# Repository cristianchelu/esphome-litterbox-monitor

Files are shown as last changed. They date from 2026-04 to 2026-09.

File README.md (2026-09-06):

# ESPHome Litterbox Monitor

A DIY smart litterbox: four load cells under the box, an HX711, and an
ESP32 running ESPHome. A state analyzer on the chip turns the raw 10 Hz
weight signal into everything listed below — no camera, no cloud, no
external compute — and surfaces it in Home Assistant as native sensors,
buttons, and actions.

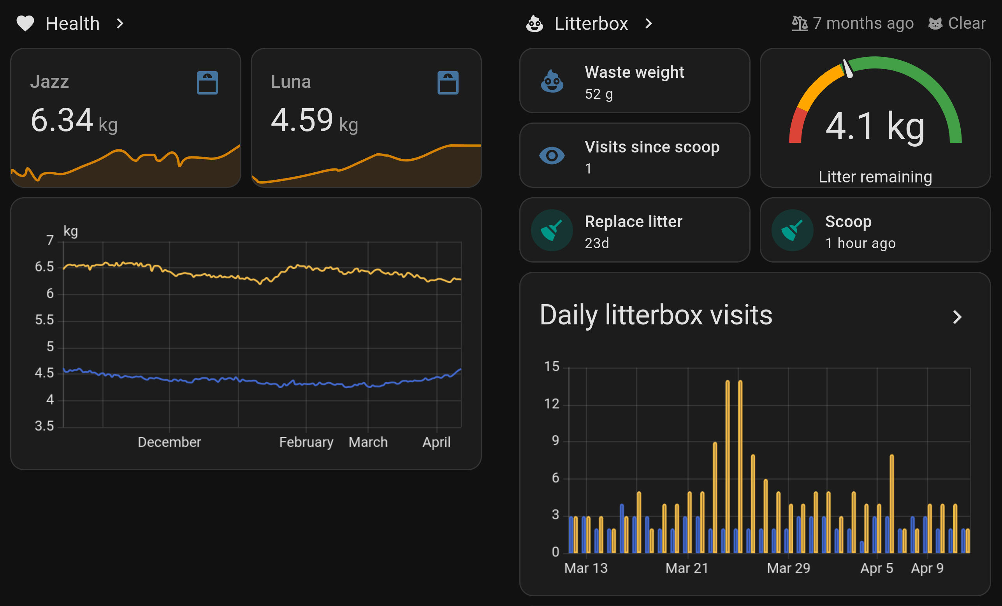
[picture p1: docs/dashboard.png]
Dashboard Overview


## Features

- **Knows which cat is which.** Identifies visiting cats by weight (up to 5)
  and tracks each cat's weight over time — no collars, no cameras.
- **Logs every visit.** Per-cat daily counts of visits, pees, and poops,
  plus visit duration and total visits since the last scoop.
- ***PoopSense.*** Tells #1 from #2 using nothing but the weight signal.
  [How it works ->](docs/POOPSENSE.md)
- **Tells you when to scoop.** Tracks how much waste has piled up since the
  last clean — and detects the clean itself, so the counters reset on their
  own when you scoop.
- **Tells you when to deep clean, and notices when you do.** Configurable
  reminder for full litter changes; put the washed box back empty and the
  timer restarts on its own. [How it works ->](docs/BOX_TRACKING.md)
- **Watches the litter level.** Estimates how much litter is left in the box
  so you know when to top up, and counts each bag you pour in.
- **Takes care of itself.** Re-zeroes against the bare board whenever the box
  comes off, and tells a scoop from a top-up from you lifting the whole thing
  to clean underneath.

## What You Need

### Load cells

- 4× strain gauge load cells, one per corner of the baseboard (commonly
  available on AliExpress); 5-12.5 kg each covers most setups.
- Sizing is a balancing act: strong enough to survive the cat's landing,
  small enough that PoopSense can still see grams. For a typical
  single-cat setup, 4× 6-8 kg cells hit the sweet spot.
- The full math — sizing formula, worked examples, and resolution table —
  lives in the **[load cell sizing guide](docs/LOAD_CELLS.md)**.

### Load cell amplifier (HX711)

- Any HX711 breakout board will work, BUT:
- Boards with separate `VCC` (5V for load cells) and `VDD` (3.3V for ESP32 logic) are recommended for best accuracy.
  - Recommended, known good example: [Sparkfun HX711 v1.1](https://www.sparkfun.com/sparkfun-load-cell-amplifier-hx711.html)
  - _BEWARE_ Some no-name breakout boards have separate `VCC` and `VDD` pins but
    electrically tie them together. Supplying 5V to these _will_ kill the esp chip.
    Validate these with a multimeter before applying power.

### ESP32

- Use a variant with a **hardware FPU**: the classic ESP32 (what the
  config targets and the development build runs) or the ESP32-S3.
- PoopSense leans on float math — per-sample filtering at 10 Hz and
  standard-deviation crunching at 0.1 g precision after every visit — so
  variants that emulate floats in software (S2, C3, C6) are untested.

### Litterbox and base

- For large breeds, the [IKEA SAMLA 79x57x18 cm/55 l](https://www.ikea.com/us/en/p/samla-box-with-lid-clear-s39440814/#content)
  is a good DIY litterbox.
- Can be paired with a suitable [IKEA KOMPLEMENT](https://www.ikea.com/gb/en/p/komplement-shelf-white-90277961/)
  shelf as a base.

### Calibration tools

You'll also want these on hand for the calibration step later:

- A known good kitchen scale.
- A bathroom scale (for weighing the cats).
- Calibration weights adding up to roughly your everyday load — box +
  litter + cat (~20 kg on the XL build). Several small water bottles work
  great; one big jug does not — see [Calibration](#calibration) for why.

## Assembly

Follow this great [SparkFun HX711 Hookup Guide](https://learn.sparkfun.com/tutorials/load-cell-amplifier-hx711-breakout-hookup-guide/all)
for wiring the load cells to the HX711 and mounting them under the baseboard.

Wire the HX711 to the ESP32. The configuration defaults to:

| HX711 pin | ESP32 pin |
|---|---|
| `DOUT` / `DT` | `GPIO16` |
| `SCK` / `CLK` | `GPIO4` |

You can use different pins — just update the `hx711` sensor section of the
YAML to match your wiring.

## Firmware Setup

1. Clone this repo (or copy both [`litterbox-monitor.yaml`](litterbox-monitor.yaml)
   and [`state_analyzer.h`](state_analyzer.h) into the same directory — both
   files are required).

2. Create a `secrets.yaml` next to them defining:
   `wifi_ssid`, `wifi_password`, `litterbox_api_key`, `litterbox_ota_password`,
   and `litterbox_ap_password`.

3. Edit the `substitutions` block at the top of the YAML:

   - **`cats`** — your cat names (e.g. "Fluffy", "Whiskers", "Mittens").
     1-5 cats are supported; add or remove entries as needed. Only the cats
     you define will have corresponding weight and daily visit sensors in
     Home Assistant, so configure this before first flashing. (After
     flashing, you'll set each cat's weight with the `set_cat_weight`
     action — see [Calibration](#calibration).)
   - **`timezone`** — your local timezone (used by the daily counters).

4. If you wired the HX711 to different GPIO pins, update the `hx711` sensor
   section accordingly (see [Assembly](#assembly)).

5. Flash with ESPHome as usual.

## Calibration

1. Gather calibration weights adding up to roughly what the cells will
   carry day to day — box + litter + cat (~20 kg on the XL build) — and
   measure them to the nearest gram in batches your kitchen scale is
   comfortable with (2 L bottles, two at a time, on a "5 kg max" scale).

   Several small bottles at working load beat one big jug: scales are
   only accurate mid-range — [here's why](docs/LOAD_CELLS.md#the-calibration-weight).

2. Set the `Calibration Known Weight` number entity to the weight
   you measured (in grams).

3. Make sure the constructed base is **without anything on top**, resting on
   a **flat and level** surface. Use shims if you need to.

4. Press the `Calibrate Scale` button. This will capture the zero point (tare).

5. Place the known weights on the base and press the `Calibrate Scale`
   button again. This will complete the calibration process.

   The "Raw weight" sensor should now read the weight you placed on it,
   and the "Calibration Last Performed" sensor should read the current time.
   If this is not the case, consult the ESPHome logs for errors and repeat
   steps 2-5.

6. ***Optional*** Fill in "Empty Box Weight" number entity to the weight of the
    empty litterbox (in grams). This will improve the accuracy of the
    "Litter Remaining" sensor, and it is how a deep clean is recognised: the
    box coming back within 150 g of this weight. You can place the box on the
    monitor and read the "Raw weight" sensor to get this value.

7. Set the litterbox on top, add the litter and trigger the `Reset clean` button.

   ***Optional*** Copy the "Litter Remaining" reading into the "Full Litter
   Weight" number entity to get "Litter Level" percentage estimates.

8. Take the approximate weight of your cats (within 10%).

   This can be easily done with weighing yourself on a bathroom scale,
   then weighing yourself again while holding each cat, and
   subtracting the difference.

   Use the `set_cat_weight` action within Home Assistant to set
   an initial value for each cat's weight, in the order you defined them
   in the configuration (see [Actions](#actions-services) below).

That's it — the monitor is ready to use.

## Reference

### Sensors and Entities

- **Cat 1-5 Weight:** Last weight stored for each cat when PoopSense identifies
  them on a visit (only enabled cats are visible).
- **Cat 1-5 Daily Visits:** Number of visits per day for each cat (only enabled cats are visible).
- **Cat 1-5 Daily Pee:** Number of urination events today for each cat (only enabled cats are visible).
- **Cat 1-5 Daily Poops:** Number of defecation events today for each cat (only enabled cats are visible).
- **Elimination Type:** Text sensor reporting `no_elimination`,
  `urination`, `defecation`, `both`, or `unknown` after each analyzed activity.
- **Event Duration:** Seconds for the activity window that was analyzed (updated
  when PoopSense runs at the end of activity).
- **Waste Weight:** Estimated total accumulated waste (grams) since last clean.
- **Litter Remaining:** Estimated remaining litter (kg).
- **Litter Level:** The same estimate as a percentage of "Full Litter Weight".
  Unavailable until you set that number.
- **Visits:** Number of cat visits since last clean.
- **Deep Clean Timer:** Days left until next recommended deep clean / litter change.
- **Deep Clean Due:** The same deadline as a timestamp, so it survives reboots
  on both ends and shows up before the clock has synced.
- **Calibration Last Performed:** Timestamp of the last completed scale
  calibration. Unavailable until one has been run.
- **Litter Added:** Grams poured in at the last top-up or deep clean.
- **Maintenance:** Event entity that fires `scoop`, `top_up`, `deep_clean` or
  `lifted` (the whole monitor was picked up and put back) once the counters
  have been updated. Use it as an automation trigger.
  [How it works ->](docs/BOX_TRACKING.md)
- **Cat Weight:** Diagnostic sensor (disabled by default) showing the cat weight
  in kg from the last PoopSense result.
- **Elimination Std Dev:** Diagnostic; the standard deviation (grams) of the
  elimination window PoopSense classified last. Compare it with the
  Classification Threshold when tuning.
- **State Machine:** Diagnostic text sensor with the analyzer's current
  phase: `empty`, `entering`, `occupied`, `eliminating` or `gap`.
- **Occupancy, Activity, Vibration:** Diagnostic sensors for physical presence,
  combined activity, and scale jitter.
- **Cat Event:** Diagnostic occupancy-style hint when tared weight is close to a
  known cat for 2+ seconds (used internally for activity; PoopSense does the
  full visit analysis when activity ends).
- **Box State:** Diagnostic text sensor: `normal`, `lifted` (monitor in the
  air), `off` (bare board) or `empty` (washed box back, nothing in it yet).
- **Measured Box Weight:** Diagnostic; what the empty box weighed when it last
  came back from a deep clean, to compare with the Empty Box Weight setting.
- **Zero Drift:** Diagnostic; what the bare board read the last time the box
  was off, before the zero was corrected.
- **Raw/Unfiltered/Tared Weight:** Diagnostic weight readings.
- **Analog sensor value:** Diagnostic (disabled by default); the raw HX711
  count before calibration is applied.
- **WiFi Signal:** Diagnostic RSSI in dBm, published once a minute as the median
  of four samples.

### Number Entities

- **Litter Change Interval:** Configure the number of days between deep clean reminders (7-30 days, default: 30).
- **Classification Threshold:** Standard deviation threshold (in grams) that separates urination from defecation. The default of 4 g works well out of the box; raise it if defecation events are being over-reported, lower it if they're being missed.  See [PoopSense](docs/POOPSENSE.md) for details.
- **Calibration Known Weight:** Weight of calibration objects used during scale setup.
- **Empty Box Weight:** Weight of the empty litterbox for improved litter remaining calculations. Also what deep-clean detection compares against; left at 0, deep cleans are not detected.
- **Full Litter Weight:** How much litter (in kg) a freshly filled box holds — what the "Litter Level" percentage counts as 100%. Left at 0, that sensor stays unavailable.

### Buttons

- **Reset Deep Clean Timer:** Resets the deep clean countdown.
- **Reset Clean:** Resets tare, litter, waste, and visit counters.

  Only required if the automatic clean detection failed.
- **Calibrate Scale:** Runs the two-step calibration: first press tares the
  bare board, second press (with the known weight on) sets the span. See
  [Calibration](#calibration).

### Actions (Services)

- `set_cat_weight`: Set a cat's weight manually via Home Assistant or API.
  - Parameters: `cat` (int, 1-5), `weight` (float)
  - Example: To set Cat 1's weight to 5.2kg, call `set_cat_weight` with `cat=1`, `weight=5.2`.

### Synchronize Multiple Litterboxes

Running more than one litterbox? Keep the cat weights in sync with a small
Home Assistant automation: when a cat's weight updates on one box, call
`set_cat_weight` on the others.

## Roadmap

- [x] Runtime assisted calibration.
- [x] Easier adding/removing of pets.
- [x] Distinguish urination/defecation/no-waste events.
- [x] Automatic zero calibration whenever the box comes off the board.
- [ ] Calculate trends and alert for outliers.
- [ ] Distinguish cats of similar weight.
- [x] Automatic deep clean detection.
- [x] Litter top-up detection.
- [ ] Error state detection (debris stuck underneath, box misaligned)

## Acknowledgements

- [Andy Bradford's Blog post](https://andybradford.dev/2022/06/02/internet-of-poop-how-and-why-i-built-a-smart-litter-tray/)
  for the initial inspiration
- [markusressel/ESPHome-Smart-Scale](https://github.com/markusressel/ESPHome-Smart-Scale) for
  the auto-tare smart scale code
- [DIY Cat Village](https://www.youtube.com/watch?v=PIszxXKy8H4) Youtube channel for the IKEA litterbox hack
- [Purina Petivity](https://www.petivity.com/products/smart-litter-box-monitor)
  for not offering an XL version and propelling this DIY project.

## Contributing

Feel free to open an issue or pull request.

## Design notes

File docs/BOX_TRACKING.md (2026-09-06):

# Box Tracking

PoopSense figures out what the cat did. Box tracking figures out what *you*
did: scooped, topped up, deep cleaned, or picked the whole thing up to clean
under it. Each of those leaves a shape in the weight signal that a cat can't
make, and the firmware uses them to keep the litter and waste counters right
without being told.

## How it works

Everything runs on the **absolute** weight (calibrated, not tared), so the
bare board reads 0 g and an empty box reads "Empty Box Weight". That makes
the shapes unambiguous where event-relative deltas aren't:

| absolute reading | meaning |
|---|---|
| below -1 kg | whole monitor is in the air (frame hanging from the cells) |
| within 300 g of zero, stable | bare board, box is off |
| within 150 g of Empty Box Weight, stable, after the box was off | box came back empty |
| rising in steps, then dead still | litter poured in |

The other trick is telling litter from a cat without knowing what either
weighs: **nothing alive holds a 1 s standard deviation under 1 g for 30 s**.
The stillest cat in the recorded visits managed 11 s. Poured litter holds it
forever. So a rise that stays inert for 30 s is litter, even if the bag
happens to weigh exactly what your cat does.

`BoxMonitor` in [state_analyzer.h](../state_analyzer.h) sees every sample,
not just during events, because the interesting moments straddle event
boundaries (box leaves in one event, comes back in the next). It tracks two
things:

- **Box state:** `normal`, `lifted`, `off` or `empty`, from the table above.
  `off` and `empty` need the level held for 3 s. Absence latches: once the
  box is gone it stays gone until something stable shows up on the board
  again, and the tare is held the whole time.
- **Plateaus:** every stretch of at least 2 s with σ < 15.8 g, as mean,
  length and sigma. The classifier reads an event as a ladder of plateaus.

### The verdict

When an event ends, before the tare moves, the first rule that fits wins:

1. **Box still absent.** No verdict yet. Tare stays where it was.
2. **Box came back empty** (within 150 g of Empty Box Weight, held 3 s)
   → `deep_clean`. Litter weight becomes whatever has gone in since, waste
   and visits reset, deep-clean timer restarts.
3. **Monitor lifted and set back** within 100 g of where it was → `lifted`.
4. **Box off and back** between -20 g and +100 g of where it was → `lifted`.
5. **Plateaus never drop** (by more than 50 g) from the lowest point of the
   event, at least 300 g gained, last 30 s inert → `top_up`, measured from
   that lowest point. If the lowest point is a scoop's worth below where the
   event started, a `scoop` is reported alongside.
6. **At least 20 g lighter, no cat matched**, and either the event ran 30 s
   or the box left the board → `scoop`.

Otherwise it's a plain cat visit (or nothing). A maintenance verdict
overrides the cat analysis: if a bag went inert on the scale, it was a bag,
whatever the weight matcher thought.

A rise that goes inert also ends the event on the spot instead of waiting
for the inactivity timeout.

### Zero check

Whenever the box is off and the bare board holds stable for 3 s, whatever it
reads is drift, and it gets folded into the calibration offset. Published as
"Zero Drift". Only the zero moves, the span still comes from calibration. A
board more than 300 g from zero is left alone on the assumption something
is wedged under it.

All thresholds are substitutions at the top of the YAML:
`box_off_tolerance`, `box_empty_tolerance`, `monitor_lift_threshold`,
`lift_return_tolerance`, `min_top_up_weight`, `top_up_settle_time`, plus
`min_clean_event_weight` and `min_clean_event_duration` for scoops.

## Troubleshooting

Most of these come down to the tracker only having one signal to work with.
It can't see hands, scoops or bags, only mass and stillness, so a few
ordinary things look the same to it.

**Scoop not registering.** The event ran under 30 s and the box stayed on
the board, so the tracker can't tell it from a bump. The scale is still
tared afterwards, nothing accumulates wrongly, but the counters don't reset.
Lower `min_clean_event_duration`, or lift the box while scooping: an absence
is proof enough and the duration requirement goes away.

**Scoop not registering, small amount.** Less than 20 g came out, which is
below the floor for a scoop. `min_clean_event_weight` sets it.

**Scoop logged after just moving the box.** The box came back more than
20 g lighter. Litter clings to the rim, sticks to the scoop, gets kicked out
in transit, and 20 g is not much. This is the scoop floor firing, not the
lift tolerance, so `min_clean_event_weight` is the knob to raise.

**Top-up not registering.** Three common causes:

- The last 30 s of the event weren't inert. Leveling, stirring or tapping the
  box keeps the signal moving, and stillness is the only thing that proves a
  bag isn't a cat. The pour needs a quiet 30 s after it.
- Something over 50 g came off after the pour, such as a scoop that was
  resting on the rim. The plateau ladder has to stay monotonic from its
  lowest point, so that drop disqualifies it.
- Less than 300 g went in. `min_top_up_weight`.

**Top-up amount looks wrong.** It's measured from the lowest plateau in the
event, not from where the event started, so scooping before the pour isn't
subtracted from the bag. A `scoop` event fires alongside when that happens.

**Top-up logged with nobody near the box.** Something inert sat on it for
30 s: a bag on the lid, the scoop on the rim. To the tracker that is
indistinguishable from litter. Removing it again reads as a scoop.

**Visit vanished, top-up logged instead.** The pour started within a few
seconds of the cat leaving, before the event closed, so both landed in one
event and the maintenance verdict took precedence. Waiting for the state to
read "empty" before refilling keeps them apart.

**Deep clean not detected.** In order of likelihood:

- Empty Box Weight isn't set. The tracker still sees the box leave and
  return but has no way to tell an empty box from a scooped-down one.
- The box came back with something in it: the scoop, a bag, a liner. More
  than 150 g over the empty weight reads as "not empty".
- Litter went in less than 3 s after the box was set down. The empty level
  has to hold for 3 s to register, and a pour starting before that erases
  it.
- Empty Box Weight is stale. A washed box weighing a few grams more wet is
  within the 150 g tolerance; a different box or a heavy new liner may not
  be.

**Deep clean detected, timer didn't restart.** The clock wasn't synced at
the time (the log says "Deep clean not stamped"). Counters still reset,
only the date is skipped.

**Zero Drift jumps around.** The zero check fires whenever the bare board
holds still within 300 g, and it takes whatever is there as the new zero. A
lid, a mat or a hand resting on the board while the box is off gets folded
into the offset. If it has drifted, re-running calibration resets it.

**Everything reads "lifted".** The absolute weight is below -1 kg, which
the tracker interprets as the frame hanging from the cells. With the box
off the raw reading should be near zero; if it isn't, suspect a cell or the
calibration offset.

**Boot with the box off.** The state reads `normal` for the first second
regardless, until the stability window fills. Harmless; the first log line
just isn't meaningful.

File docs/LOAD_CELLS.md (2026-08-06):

# Choosing Load Cells

The monitor asks two things of its load cells, and they pull in opposite
directions:

1. **Strong enough** to take the heaviest realistic hit — a cat landing
   off-center — without damage.
2. **Fine enough** that the HX711 can still resolve the grams-level
   variance [PoopSense](POOPSENSE.md) classifies on.

Oversizing feels safe but silently costs the second one: every kilogram
of rated capacity you don't need makes each ADC count coarser. This guide
gives you a capacity floor from the physics and a resolution ceiling from
the classifier — pick something between them.

## The Capacity Floor

Add up everything the cells will ever carry, with headroom:

> (baseboard + litterbox + litter + (heaviest cat × jump factor)) × 1.5

Pick the **jump factor** to match your cat, not the worst cat imaginable.
Measured landing forces for cats run about 1.5-3× body weight:

| Jump factor | Your cat |
|---|---|
| × 1.5 | Gentle stepper — walks in, or a low-sided box |
| × 2 | Typical — hops the rim with some enthusiasm |
| × 3 | Launcher — dives in from the nearest furniture |

The fixed **× 1.5** covers off-center loading. The four corners share the
load evenly only when it's centered; a cat landing near one corner can
push close to half the total force through a single cell.

Divide the result by four for the per-cell rating.

Don't pad beyond this. Hits rarer and harder than the formula assumes
land within the cells' safe-overload rating (typically 120-150% of
capacity) — a third layer of protection that's already in the hardware.

## Worked Examples

- **Average cat, typical jumper:** (1 kg baseboard + 0.5 kg box +
  2.5 kg litter + (5 kg cat × 2)) × 1.5 = **21 kg** total →
  four 6-8 kg cells (24-32 kg combined).
- **Large gentle cat, XL box:** (5 kg baseboard + 1.5 kg box +
  5 kg litter + (10 kg cat × 1.5)) × 1.5 ≈ **40 kg** total →
  four 10 kg cells (40 kg combined). Note the shelf: a KOMPLEMENT
  baseboard weighs 5.1 kg on its own and eats real margin.
- **Same cat, launcher habits (× 2):** ≈ **47 kg** total → four 12.5 kg
  cells (50 kg combined). At that rating, resolution gets borderline at
  3.3 V excitation, so this is the setup where a 5 V-capable HX711 board
  stops being optional (see the table below).

For reference, the development build — 6.5 kg non-jumping cat, 1.35 kg
box, 6 kg litter, 5.1 kg KOMPLEMENT shelf — comes out at ≈33 kg with the
× 1.5 factor. It has run on four 8 kg cells (32 kg combined) for two
years of daily use.

## The Resolution Ceiling

Presence detection and plain weight tracking work on almost any sensibly
sized cells. Waste-type classification doesn't: PoopSense separates
urination from defecation on roughly **0.5 g** of standard-deviation
daylight (see [its write-up](POOPSENSE.md#load-cell-selection) for where
that number comes from), so quantization matters. Rule of thumb:

- **<= 0.25 g/count**: plenty of room
- **0.25-0.5 g/count**: workable, tighter on edge cases
- **> 0.5 g/count**: too coarse — the classifier starts guessing

### Resolution Table

For common 4-cell bridge configurations. **g/count** values below are
**ballparks** (typical cheap cells, HX711 gain 128, real-world usable
20-bit resolution):

| Cell Rating | g/count @ 3.3V | Verdict @ 3.3V | g/count @ 5V | Verdict @ 5V |
|---|---|---|---|---|
| 4× 5kg = 20kg | ~0.12 | ✅ | ~0.08 | ✅ |
| 4× 8kg = 32kg | ~0.19 | ✅ | ~0.12 | ✅ |
| 4× 10kg = 40kg | ~0.23 | ✅ | ~0.15 | ✅ |
| 4× 12.5kg = 50kg | ~0.29 | ⚠️ borderline | ~0.19 | ✅ |
| 4× 20kg = 100kg | ~0.58 | ❌ | ~0.38 | ⚠️ borderline |
| 4× 50kg = 200kg | ~1.2 | ❌ | ~0.76 | ❌ |

"Bigger load cells just to be safe" eventually works against you: you
need cells rated high enough for the cat, the litter, and the box — but
not so high that the ADC can't resolve a few grams of variance. If the
floor and the ceiling leave you squeezed, running the cells at 5 V
excitation (with a properly isolated HX711 board — see the README's
hardware notes) buys the extra headroom.

## The Calibration Weight

Half-bridge cells are linear in the middle of their range and go wonky
near both ends. A reference weight that's small relative to the range —
say 4-5 kg on a 40 kg system — fits the calibration slope in a region
the scale never uses day to day, then extrapolates it out to where box +
litter + cat actually live. Aim the reference at the everyday load
instead, landing the scale mid-range where it's linear.

To build a 20 kg reference at gram accuracy, use several small water
bottles rather than one big jug. The kitchen scale you measure them with
has the same end-of-range problem, so weigh 2 L bottles two at a time on
a "5 kg max" scale and sum the batches. The development build was
calibrated this way, with ~20 kg of bottles.

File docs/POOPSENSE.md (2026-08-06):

# PoopSense

*Zero-AI[1] waste type recognition for smart litterboxes.*

[1] Zero AI at runtime. Plenty of AI was harmed in the making of this
heuristic.

## The Problem

Knowing whether a cat urinated, defecated, or both is genuinely useful
health data -- changes in frequency or ratio can flag UTIs, constipation,
or dietary issues early.

Most smart litterbox manufacturers offer some form of waste classification
these days -- cloud-based classifiers, camera-fed ML models, on-device
neural nets requiring multiple TOPS of compute, some going as far as
loose stool detection and color-changing pH-reactive litter for urinary
health monitoring.  These are serious products with serious hardware
budgets, and none of it is open-source.

PoopSense is not trying to compete with any of that.  It's a parallel,
open-source effort to see how far you can get with nothing but a load
cell, an ESP32, and some arithmetic.

## The Insight

While a cat is settled and actively eliminating, the scale is essentially a
very sensitive motion sensor.  The key observation:

- **Urination** is a low-motion event.  The cat holds still, and the
  scale reading barely moves.  Weight variance during this period is
  **low** (standard deviation typically < 4 g).

- **Defecation** involves periodic muscular effort.  The cat shifts, braces,
  and pushes.  These micro-movements cause the scale reading to wobble.
  Weight variance is **noticeably higher** (standard deviation > 4 g).

That's it.  The entire classifier is a single threshold on the standard
deviation of the weight signal during an elimination window.  The rest of
the machinery is just figuring out where that window actually is.

## How It Works

PoopSense rides on top of a state machine that tracks what the cat is doing
on the scale in real time, sample by sample at 10 Hz.

### The State Machine

```
EMPTY --> ENTERING --> OCCUPIED <--> ELIMINATING
  ^                      |  ^
  | timeout              |  | weight returns
  +-------- GAP <--------+--+
```

| State | Meaning |
|---|---|
| **EMPTY** | Nothing on the scale. Waiting for weight to cross the entry threshold. |
| **ENTERING** | Something stepped on. Weight is rising and not yet settled. |
| **OCCUPIED** | Weight is present and roughly matches a known cat, but readings are still moving around. The cat is shifting, digging, or getting comfortable. |
| **ELIMINATING** | Weight is stable and close to a known cat value. The cat is sitting still -- likely doing its business. |
| **GAP** | Weight dropped below threshold briefly (repositioning, partial step-off). If weight returns, the session resumes; if the gap times out, the session ends. |

The transition from `OCCUPIED` to `ELIMINATING` is gated by a rolling variance
check over a 1-second window (is the cat holding reasonably
still?), combined with the weight being within 10% of a known cat.
When the cat starts moving again, it drops back to `OCCUPIED`.

This means a single visit can have **multiple** `ELIMINATING` periods --
the cat may urinate, shift, then defecate.

### Post-Processing

When activity ends, the raw state timeline goes through cleanup:

1. **Merge**: Short `OCCUPIED` blips (< 1.5 s) sandwiched between two
   `ELIMINATING` periods get absorbed into one continuous elimination --
   these are just transient body shifts, not real state changes.
2. **Downgrade**: `ELIMINATING` periods shorter than 5 seconds are demoted to
   `OCCUPIED` -- too brief to be a real elimination event.
3. **Collapse**: Consecutive periods of the same state get merged.

### Standard Deviation Calculation

For each surviving `ELIMINATING` period, the population standard deviation of
the raw weight samples is computed.  The first and last 10 samples (~1 s
each) are trimmed to avoid transition noise from the cat settling in or
getting up.

### Classification

| Condition | Result |
|---|---|
| No `ELIMINATING` periods survived | `no_elimination` |
| One period, std dev < 4 g | `urination` |
| One period, std dev >= 4 g | `defecation` |
| Two periods, one below and one above | `both` |
| Anything else | `unknown` |

The 4 g threshold (`SA_URINATION_STD_DEV_THRESHOLD_G`, `"Classification Threshold"`) 
is the only tunable for classification, and in practice it separates 
the two behaviors cleanly.

## Cat Identification & Weight

Cat identification and cat weight measurement are two different problems.
They use different data, tolerate different amounts of noise, and fail in
different ways -- so they're solved separately.

### Identity

Identity is a majority-vote across the entire visit.  Every sample in
`OCCUPIED` or `ELIMINATING` is matched against configured cat profiles
(same 10% band used elsewhere).  The cat with the most matching samples
wins the attribution; if no profile was ever in range, the visit stays
unattributed.

### Visit Weight

Visit weight only considers stable `ELIMINATING` samples, for the same
reason a kitchen scale has a stability indicator: if the load is still
moving, the number isn't meaningful yet.  Samples where the cat is
shifting, digging, or repositioning stay within the 10% identity band
and count toward the vote, but folding them into a weight average
degrades the figure over time.

Of the qualifying stable periods, the longest continuous stretch is
selected and its mean reported.  This is computed independently of the
identity vote.

## Validation

The threshold and state machine were developed against ~2 months of
continuous data from a two-cat household, with every event manually tagged
via a webcam pointed at the litterbox.  Not a huge sample, but enough to
tune the heuristics with confidence that no events were missed or
mislabeled.

Plotting every tagged event by its elimination-phase standard deviation
tells the story pretty clearly -- urination clusters low, defecation
sits higher, and the gap between the two is real if not enormous.

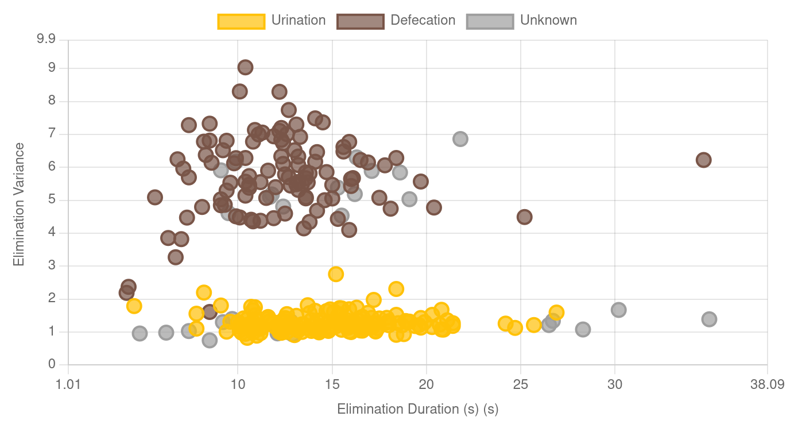
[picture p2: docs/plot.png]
elimination variance by tagged waste type


Two representative visits show what the state machine actually sees.
Weight signal and rolling variance are overlaid with the state timeline
-- you can see the `ELIMINATING` window land right where the cat holds
still, with variance near zero for urination and visibly elevated for
defecation.

| Urination | Defecation |
| --- | --- |
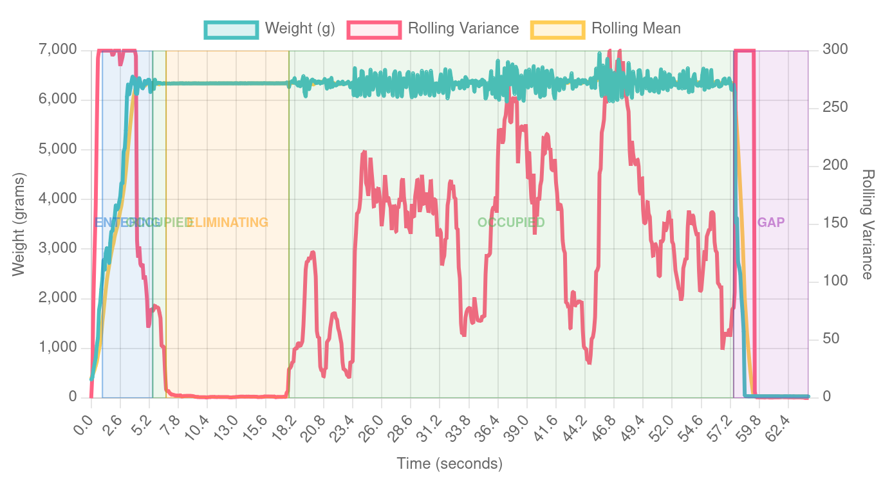
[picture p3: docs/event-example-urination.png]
Example visit classified as urination
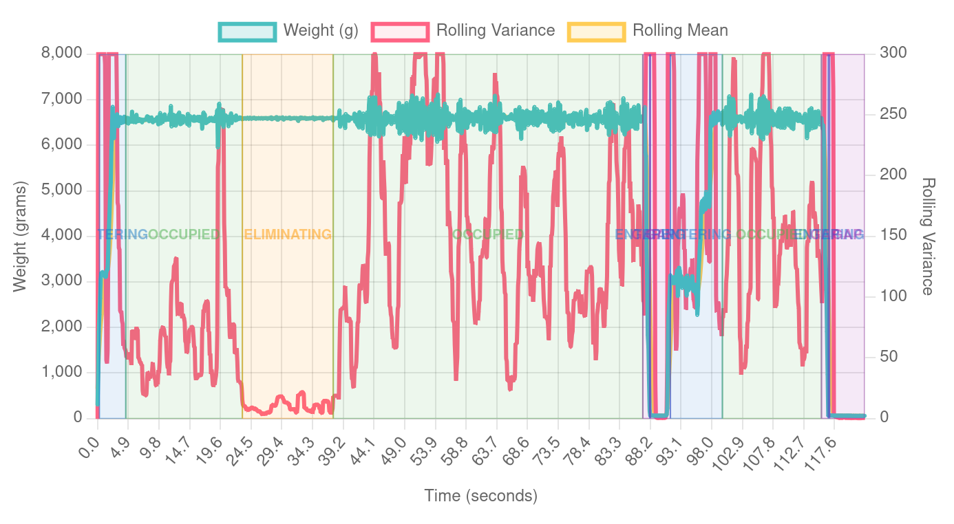
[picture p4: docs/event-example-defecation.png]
Example visit classified as defecation
|  |  |

## Known Limitations

- **Cats of similar weight** (within ~10%) can't be reliably distinguished.
  This is a fundamental limitation of weight-only identification.

- **Very short eliminations** (< 5 s) are filtered out to avoid false
  positives.  A cat with unusually fast events may occasionally get
  `no_elimination`.

- **Vigilant cats produce false positives.**  A cat that sits motionless
  while scanning for threats looks identical to a cat that's urinating --
  both present as low-variance stillness on the scale.  If your cat tends
  to freeze and surveil mid-visit, expect occasional phantom urination
  events.

- **Diarrhea reads as urination.**  The variance signal depends on the
  physical effort of normal defecation -- the cat braces and shifts, and
  the scale picks that up.  Loose stool passes without any of that, so
  the reading looks identical to urination.  This is worth keeping in
  mind if you're monitoring a cat with GI issues -- the data will
  under-report defecation during flare-ups.

- **The 4 g threshold is empirical.**  It was derived from two cats that
  happened to cluster neatly on either side of it.  Different cats, different
  scale builds, or the same cat at a different age may shift where those
  clusters land.  Different noise floors also play a role.

- **Scale hysteresis hides very small deposits.**  Load cells have a small
  amount of mechanical hysteresis -- a cat can enter, leave nothing, and
  exit, yet the reading shifts by 10-15 g.  A minimum waste threshold is
  applied to avoid false positives, which means genuinely tiny deposits
  (e.g. a few grams of urine during a UTI bout) fall below the noise
  floor and go undetected.  This is a hardware limitation, not a software
  one.

## Load Cell Selection

PoopSense only works as well as the underlying weight signal.  If the
load cell plus ADC combination is too coarse, the classifier can't see
the difference it's looking for.

The decision gap is narrow.  In practice:

- Urination lands around **1-3.5 g** standard deviation
- Defecation lands around **4-10 g**
- The cutoff sits at **4 g**

That's roughly **0.5 g** of daylight between a noisy urination event
and the defecation threshold.  If quantization eats into that margin,
near-threshold events become coin flips -- as a rule of thumb, the
scale needs **0.25 g/count or better** to stay comfortably clear.

Which cell ratings and excitation voltages actually deliver that -- and
how to size the cells for the cat in the first place -- is covered in
the [load cell sizing guide](LOAD_CELLS.md), resolution table included.

## Future Work

**Adaptive threshold calibration.**  The fixed 4 g threshold is a
convenient starting point, but it's really a midpoint between two
clusters -- low-variance (urination) and high-variance (defecation) --
that are specific to each cat and setup.  With a short bootstrapping
period (i.e. a few manually-tagged events of each type), it should be possible
to derive per-cat cluster centers and compute the optimal separator
automatically.  This would also allow the threshold to drift over time as
a cat ages or its habits change, rather than relying on a single static
value that happened to work for the development household.

**Post-elimination digging as confirmation.**  One signal that's visible
in the raw data but not yet exploited: after a real elimination event,
most cats will vigorously cover their waste, producing a distinctive
high-energy burst in the weight signal.  This burst is largely absent
after a non-event (spook, inspection, just passing through).

In theory, detecting a digging phase could serve as a confirmation signal
to reduce false positives from vigilant-cat scenarios.  In practice, the
state machine complexity explodes -- a cat might step out, step back in,
dig, leave, return, dig again -- and modeling all of that purely with
heuristic transitions gets unwieldy fast.  It's a promising direction, but
likely needs a different approach than extending the current state machine.

**Straining detection.**  If PoopSense detects multiple `ELIMINATING`
periods (the cat tried) but no resultant waste above the hysteresis
threshold, that's a potential straining signal worth surfacing.
Correlating this with an audio classifier for vocalization (yowling
during straining is a known distress indicator, and others are already
exploring audio-based detection) could make it more robust, though that's
firmly in sensor-fusion territory.

**Actionable insights.**  Right now PoopSense classifies and reports --
it doesn't act on what it finds.  The interesting part (trending
elimination patterns over time, flagging deviations from a cat's
baseline, alerting when something looks off) lives outside this repo,
in a separate application built to aggregate and surface that data.

In principle, this could happen on-device: an ESP32 has enough headroom
to maintain rolling baselines and fire alerts over MQTT or ESPNow,
and multi-litterbox households could synchronize state between nodes to
get a complete picture per cat.  But that's a substantial layer of
complexity on top of what is currently a sensor firmware, and it hasn't
been built yet.

## Implementation

The entire implementation lives in
[`state_analyzer.h`](../state_analyzer.h) -- a single C++ header included
by the ESPHome configuration.  No external dependencies, no network
calls, no cloud.  It runs comfortably within the memory and CPU budget
of a classic ESP32 -- provided the chip has a hardware FPU (see the
README's ESP32 notes); the math is float-heavy and software-float
variants are untested.

---

*A note on naming:* Every smart litterbox brand has a fancy trademarked
name for their waste classifier.  PoopSense is silly; the effort behind
it isn't.

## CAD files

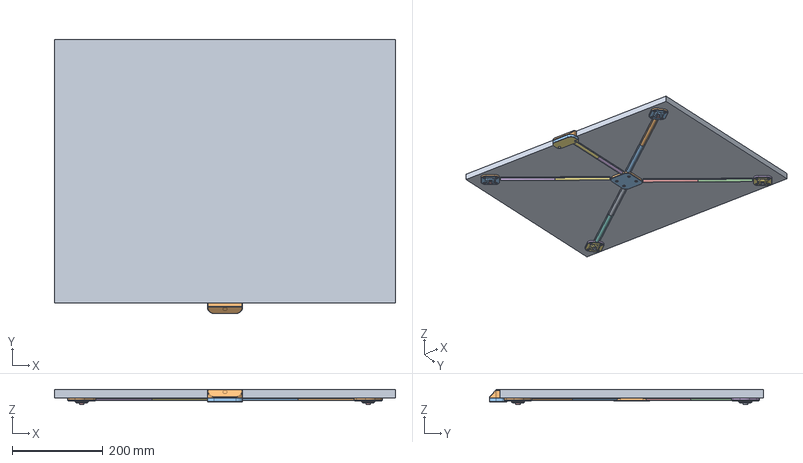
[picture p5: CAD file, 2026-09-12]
tools/cad/assembly.FCStd
750.0 x 603.0 x 32.6 mm
MDF
Shell_Top
Shell_Mid
Shell_Sleeve
Shell_TailSleeve
Shell_CapSleeve
Shell_Cap
Shell_ESP32_ref
Shell_TTP223_ref
Foot1_Base
Foot1_Cap
Foot1_CellMetal_ref
Foot1_CellFoot_ref
Foot2_Base
Foot2_Cap
Foot2_CellMetal_ref
Foot2_CellFoot_ref
Foot3_Base
Foot3_Cap
Foot3_CellMetal_ref
Foot3_CellFoot_ref
Foot4_Base
Foot4_Cap
Foot4_CellMetal_ref
Foot4_CellFoot_ref
HX_Tray
HX_Cap
HX_HX711_ref
HX_Dupont_ref
Chan_foot1_1
Chan_foot1_2
Chan_foot2_1
Chan_foot2_2
Chan_foot3_1
Chan_foot3_2
Chan_foot4_1
Chan_foot4_2
Chan_hx_brain_1
Chan_hx_brain_2

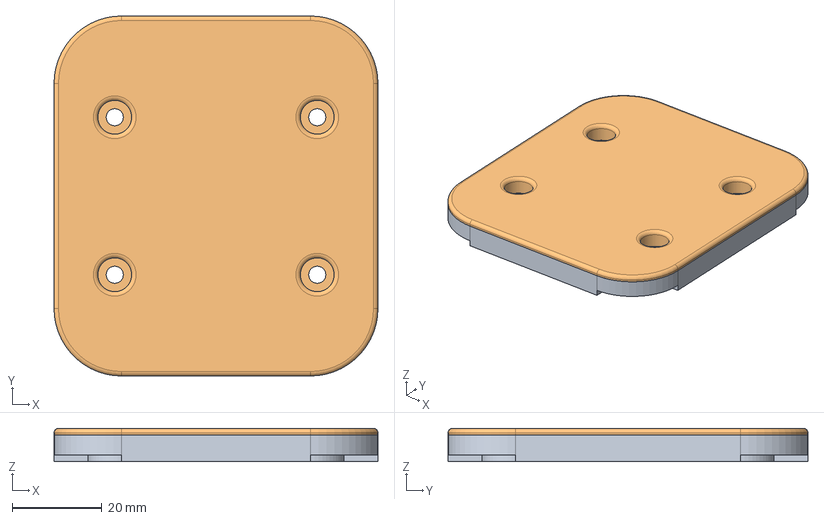
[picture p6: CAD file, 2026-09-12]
tools/cad/hx711.FCStd
72.0 x 80.0 x 7.40 mm
Tray
Cap
HX711_ref
Dupont_ref

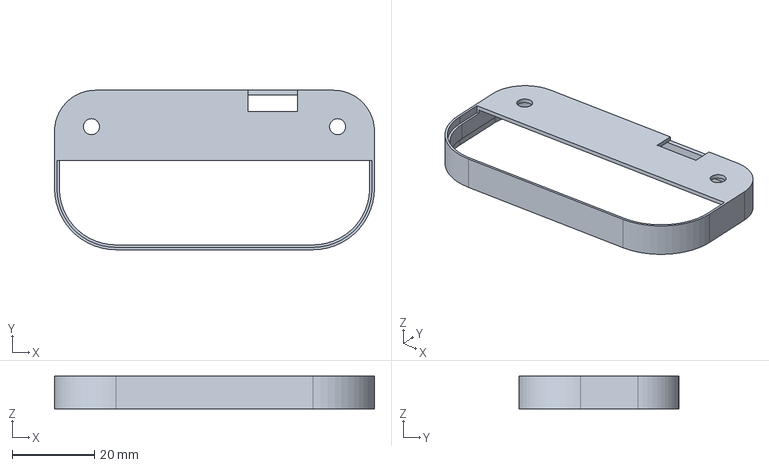
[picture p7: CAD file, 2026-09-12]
tools/cad/brain_shell_mid.step
78.0 x 38.9 x 8.01 mm

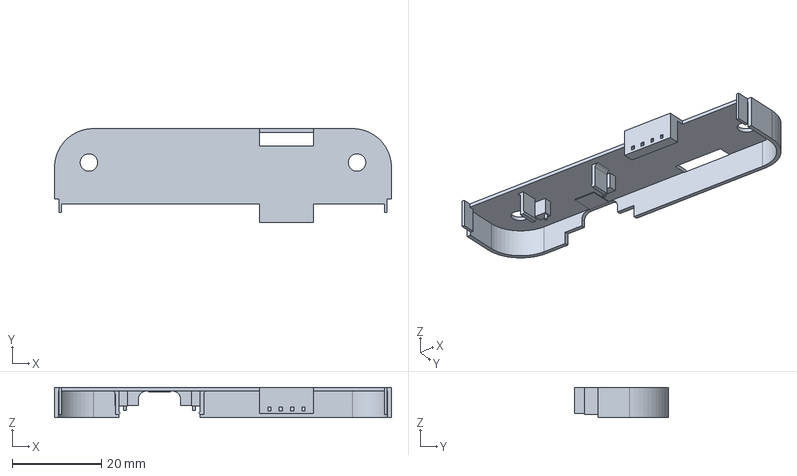
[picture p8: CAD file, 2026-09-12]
tools/cad/brain_shell_tailsleeve.step
75.4 x 21.0 x 6.81 mm

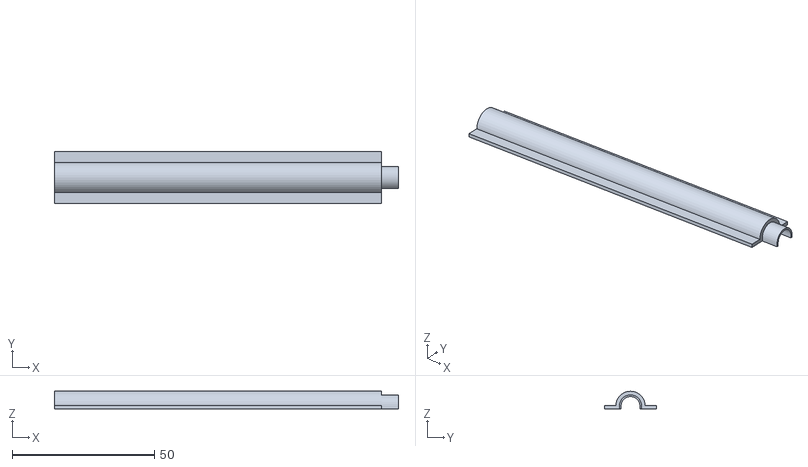
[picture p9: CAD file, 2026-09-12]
tools/cad/channel_hx_brain_1of2_115mm.stl
121.1 x 18.4 x 6.20

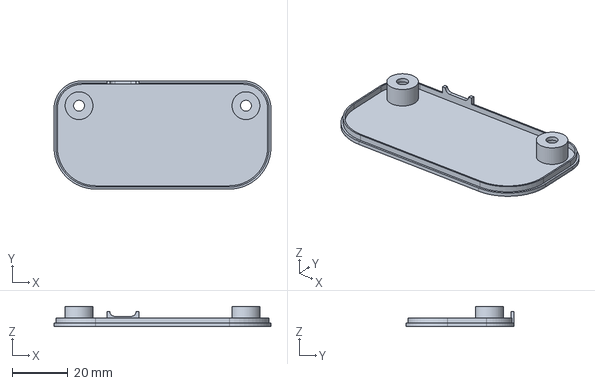
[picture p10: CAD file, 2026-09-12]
tools/cad/brain_shell_cap.step
78.0 x 38.9 x 7.21 mm

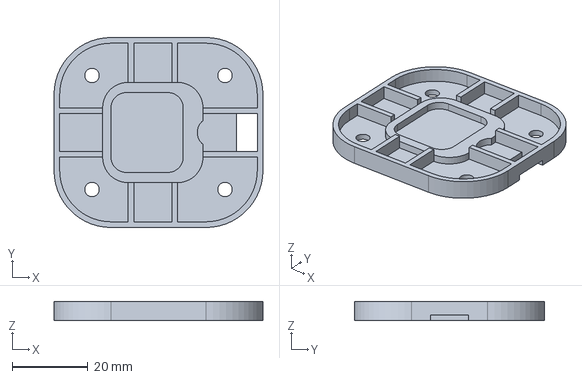
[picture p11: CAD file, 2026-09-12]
tools/cad/foot_base.step
55.0 x 50.0 x 5.10 mm

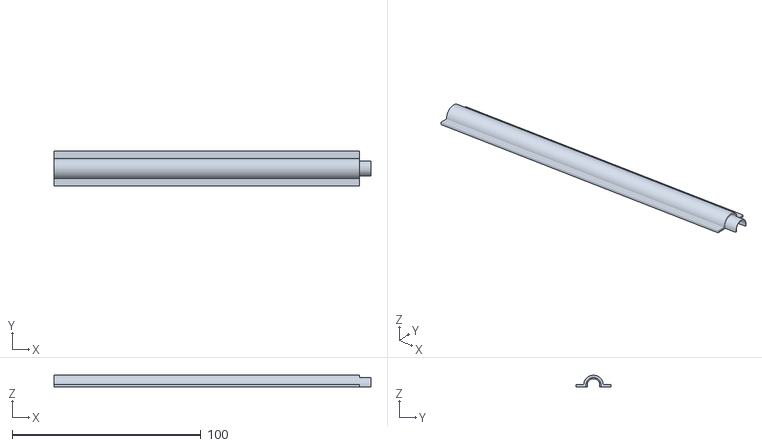
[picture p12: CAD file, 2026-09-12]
tools/cad/channel_foot_1of2_162mm.stl
167.9 x 18.4 x 6.20

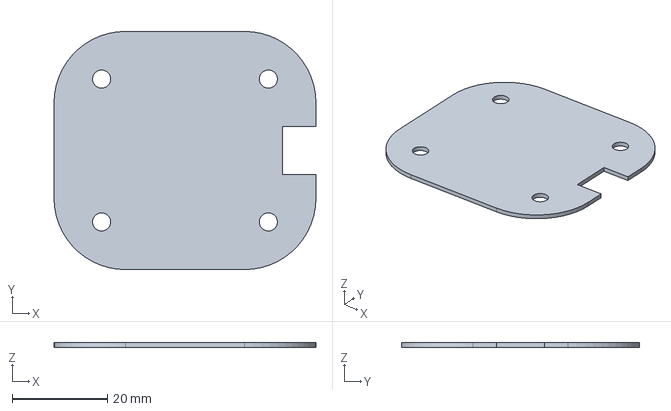
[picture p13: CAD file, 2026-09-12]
tools/cad/foot_shim_1_0.step
55.0 x 50.0 x 1.00 mm

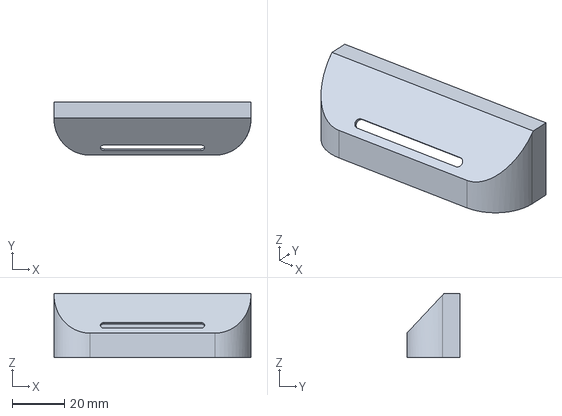
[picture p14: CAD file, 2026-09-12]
tools/cad/brain_shell_sleeve.step
75.4 x 20.4 x 24.6 mm

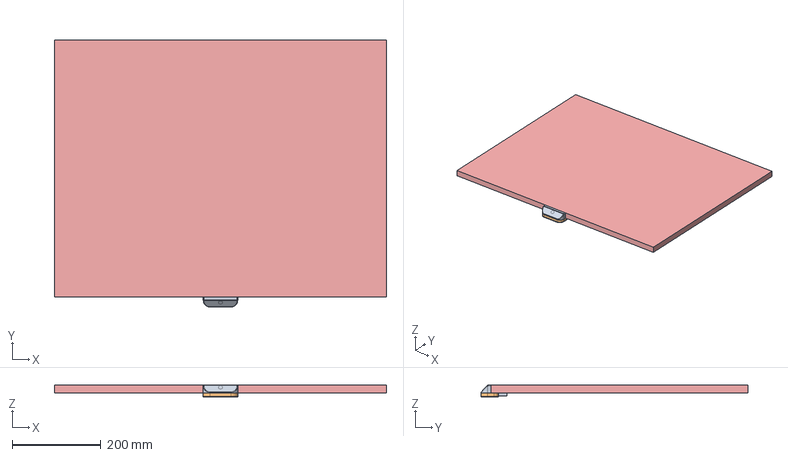
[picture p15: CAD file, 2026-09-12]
tools/cad/brain_shell.FCStd
750.0 x 603.0 x 27.2 mm
Top
Mid
Sleeve
TailSleeve
CapSleeve
Cap
ESP32_ref
LED_ref
USBplug_ref
TTP223_ref
Pins_ref
Housing_ref
MDF_ref

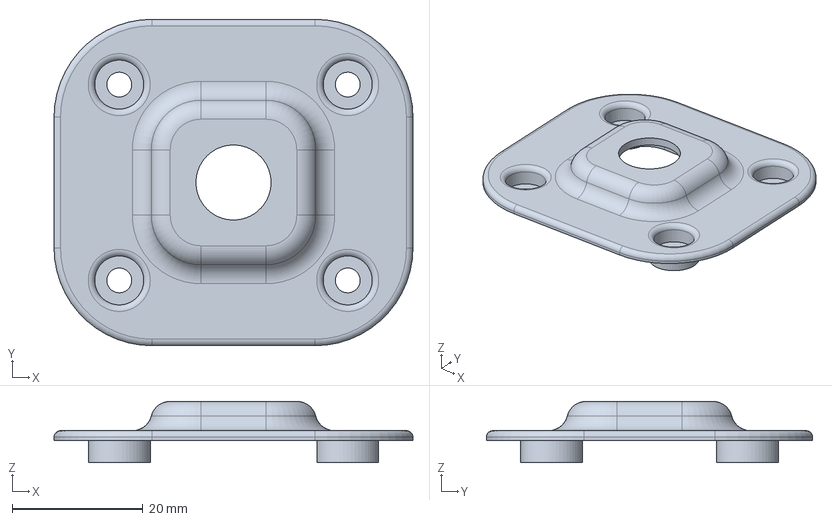
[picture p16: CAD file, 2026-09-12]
tools/cad/foot_cap.step
55.0 x 50.0 x 9.40 mm

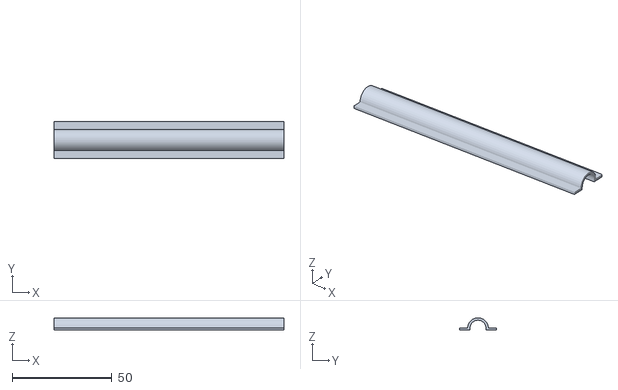
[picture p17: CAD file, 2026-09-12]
tools/cad/channel_hx_brain_2of2_115mm.stl
115.1 x 18.4 x 6.20

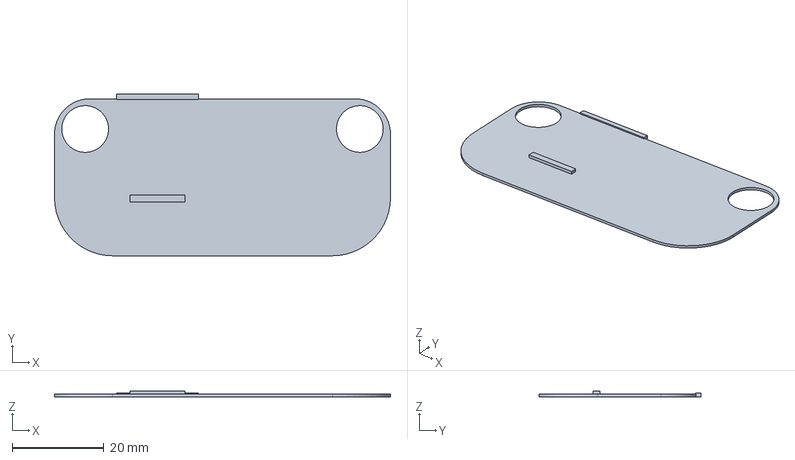
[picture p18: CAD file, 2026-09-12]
tools/cad/brain_shell_capsleeve.step
73.4 x 35.3 x 1.30 mm

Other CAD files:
tools/cad/foot.FCStd
tools/cad/channel_foot_2of2_162mm.stl
tools/cad/brain_shell_top.step
tools/cad/hx711_tray.step
tools/cad/brain_shell_cap.stl
tools/cad/brain_shell_capsleeve.stl
tools/cad/brain_shell_mid.stl
tools/cad/brain_shell_sleeve.stl
tools/cad/brain_shell_tailsleeve.stl
tools/cad/brain_shell_top.stl
tools/cad/foot_base.stl
tools/cad/foot_cap.stl
tools/cad/foot_shim_1_0.stl
tools/cad/hx711_cap.step
tools/cad/hx711_cap.stl
tools/cad/hx711_tray.stl

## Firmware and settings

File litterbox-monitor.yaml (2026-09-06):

substitutions:
  ## Configuration parameters
  ## Modify these to suit your setup

  # Cat names to be shown in the Home Assistant UI
  # Enables the corresponding cat sensors.
  # Add or remove up to 5 cats as needed.
  cats:
    - "Cat 1"
    - "Cat 2"

  # Timezone of the device, used for daily visits sensors
  # See https://en.wikipedia.org/wiki/List_of_tz_database_time_zones
  # for valid values, e.g. "Europe/Bucharest", "America/New_York", "GMT0"
  timezone: "GMT0"


  ## Internal parameters
  ## Modify these only if you know what you're doing

  # Minimum duration of a clean event to be considered valid and automatically
  # reset the waste and visits counters. Used to distinguish small bumps
  # from actual clean events. Decrease this value if quick cleaning events
  # are not detected.
  min_clean_event_duration: "30" # seconds

  #  Minimum weight threshold to consider a clean event valid.
  min_clean_event_weight: "-20" # g

  # Duration of no vibration detected before vibration sensor is considered off.
  vibration_off_delay: "4" # seconds

  # Relative weight change between two consecutive readings to consider
  # as vibration. Used to filter out small noise from the weight sensor.
  vibration_threshold: "0.020" # kg

  # Duration of no activity (vibration, cat, or occupancy) detected before
  # the event should be considered over. Compounded with the vibration delay.
  activity_off_delay: "4" # seconds

  # Relative weight change between two consecutive readings to consider
  # as a spurious measurement.
  # Used to filter out big outliers from the weight sensor.
  spike_threshold: "4" # kg

  # Duration of no vibration detected before forcing the event to be over.
  # Used as fallback when weight sensor reads above detection thresholds after
  # a litterbox event.
  event_timeout: "120" # seconds

  # Box tracking. All on the absolute (calibrated, un-tared) weight, so the
  # bare board is 0 g and the empty box is Empty Box Weight.

  # Reading this close to 0 g while stable means the box is off the board.
  # Also the zero check: whatever it reads then is drift, and gets corrected.
  box_off_tolerance: "300" # g

  # Box back within this of Empty Box Weight, after having been off, is a
  # deep clean. A washed box comes back a few grams wet; a scooped one comes
  # back kilograms heavier.
  box_empty_tolerance: "150" # g

  # Reading more negative than this means the monitor itself is in the air
  # (the frame hangs from the cells). Nothing else reads below zero.
  monitor_lift_threshold: "1000" # g

  # Box (or monitor) put back within this of where it was: nothing changed.
  lift_return_tolerance: "100" # g

  # Smallest rise reported as a litter top-up.
  min_top_up_weight: "300" # g

  # Mass that sits this long without a wobble (1 s σ < 1 g) is litter, not a
  # cat, whatever it weighs: the stillest cat on record managed 11 s. Ends a
  # top-up early and is what a rise must do to count as one.
  top_up_settle_time: "30" # seconds

globals:
  ## General state

  # Known cat weights
  - id: cat_weights
    type: float[5] # kg
    initial_value: "{0.0, 0.0, 0.0, 0.0, 0.0}"
    restore_value: True
  # Daily visits per cat
  - id: cat_daily_visits
    type: int[5] # count
    initial_value: "{0, 0, 0, 0, 0}"
    restore_value: True
  # Daily pees per cat
  - id: cat_daily_pees
    type: int[5] # count
    initial_value: "{0, 0, 0, 0, 0}"
    restore_value: True
  # Daily poops per cat
  - id: cat_daily_poops
    type: int[5] # count
    initial_value: "{0, 0, 0, 0, 0}"
    restore_value: True
  # Timestamp of last litter change
  - id: litter_changed_date
    type: time_t
    initial_value: "0"
    restore_value: True


  ## Event-related state variables

  # An event is being recorded (begin_event ran, end_event hasn't yet)
  - id: event_open
    type: bool
    initial_value: "false"
    restore_value: False

  # The previous event ended on the inactivity timeout with a cat still in
  # the box. The visit was already counted; the next event only adds waste.
  - id: suppress_visit
    type: bool
    initial_value: "false"
    restore_value: False

  # Timestamp of event start (activity first detected)
  - id: event_start
    type: time_t
    initial_value: "0"
    restore_value: False
  
  
  ## Scale calibration parameters
  
  # Auto-tare at event end
  - id: tare_value
    type: float # kg
    initial_value: "0.0"
    restore_value: True

  # Running auto-tare at idle to account for temperature drift
  - id: auto_tare_value
    type: float # kg
    initial_value: "0.0"
    restore_value: True

  # Last full calibration timestamp
  - id: calibration_timestamp
    type: time_t
    initial_value: "0"
    restore_value: True

  # Calibration tare when empty
  - id: calibration_tare
    type: float # sensor counts
    initial_value: "0.0"
    restore_value: True
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

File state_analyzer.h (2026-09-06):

#pragma once
#include <algorithm>
#include <cmath>
#include <cstdint>
#include <cstring>

static const int SA_MAX_SAMPLES = 36000;
/** Long visits can oscillate often; dropping txs breaks post_process vs TS (was 128). */
static const int SA_MAX_TRANSITIONS = 2048;
/** Must cover all tx segments before merge (short visits can exceed 64 transitions). */
static const int SA_MAX_PERIODS = 256;
/** Max RMS windows for median-RMS metric at 10 Hz over SA_MAX_SAMPLES. */
static const int SA_MOTION_HZ = 10;
static const int SA_MAX_MOTION_WINDOWS = SA_MAX_SAMPLES / SA_MOTION_HZ;
static const int SA_MAX_CATS = 5;
static const int SA_MAX_ZONES = 32;
static const float SA_URINATION_STD_DEV_THRESHOLD_G = 4.0f;
static const int16_t SA_SCALE_ABS = 1;    // 1g, identical to previous behavior
static const int16_t SA_SCALE_DELTA = 10; // 0.1g, used during OCCUPIED/ELIMINATING

/**
 * Scratch for median-RMS over eliminating windows.
 * Function-static so it lives in BSS (not the ESPHome 8 KiB loop stack / heap).
 * Single-threaded: only one finalize/replay at a time.
 */
inline float *sa_motion_rms_scratch() {
  static float buf[SA_MAX_MOTION_WINDOWS];
  return buf;
}

enum class AnalyzerState : uint8_t {
  EMPTY,
  ENTERING,
  OCCUPIED,
  ELIMINATING,
  GAP
};

enum class EliminationType : uint8_t {
  NO_ELIMINATION,
  URINATION,
  DEFECATION,
  BOTH,
  UNKNOWN
};

struct StatePeriod {
  AnalyzerState state;
  int start;
  int end;
  float std_dev;  // negative means undefined
};

struct StateTransition {
  AnalyzerState from;
  AnalyzerState to;
  int index;
};

struct StateResult {
  float cat_weight;
  float waste_weight;
  StatePeriod periods[SA_MAX_PERIODS];
  int period_count;
  EliminationType elimination_type;
  int detected_cat;  // 0-based index, -1 = unknown
};

struct ZoneEntry {
  int start;         // first sample index in this zone
  float baseline_g;  // 0.0 for absolute zones
  int16_t scale;     // SA_SCALE_ABS or SA_SCALE_DELTA
};

// Ring buffer for rolling statistics over a fixed window.
class Ring {
 public:
  Ring() : n_(0), i_(0), filled_(0) { memset(buf_, 0, sizeof(buf_)); }

  explicit Ring(int n) : n_(n), i_(0), filled_(0) {
    memset(buf_, 0, sizeof(buf_));
  }

  void push(float x) {
    buf_[i_] = x;
    i_ = (i_ + 1) % n_;
    if (filled_ < n_) filled_++;
  }

  float mean() const {
    if (!filled_) return 0.0f;
    float s = 0.0f;
    for (int k = 0; k < filled_; k++) s += buf_[k];
    return s / static_cast<float>(filled_);
  }

  // Sample variance (divides by n-1)
  float variance() const {
    if (filled_ < 2) return 0.0f;
    float m = mean();
    float s = 0.0f;
    for (int k = 0; k < filled_; k++) {
      float d = buf_[k] - m;
      s += d * d;
    }
    return s / static_cast<float>(filled_ - 1);
  }

  // Checks ALL n slots including unfilled zeros, matching the TS Array.every()
  // behavior where the buffer is pre-filled with zeros.
  template <typename Func>
  bool every(Func fn) const {
    for (int k = 0; k < n_; k++) {
      if (!fn(buf_[k])) return false;
    }
    return true;
  }

  int size() const { return filled_; }

  void reset(int n) {
    n_ = n;
    i_ = 0;
    filled_ = 0;
    memset(buf_, 0, sizeof(buf_));
  }

 private:
  static const int MAX_RING = 16;
  float buf_[MAX_RING];
  int n_;
  int i_;
  int filled_;
};

// Stores raw weight samples for post-hoc per-period variance calculation.
//
// Samples are stored in one of two encodings, tracked via a zone table:
//   Absolute zones (SA_SCALE_ABS=1):  int16_t(weight_g)          -- 1g precision
//   Delta zones (SA_SCALE_DELTA=10):  int16_t((weight_g-base)*10) -- 0.1g precision
//
// Delta zones are opened at each OCCUPIED entry; absolute zones at GAP/ENTERING.
// elimination_motion_metric() decodes per zone and applies TS median-RMS metric.
class WeightBuffer {
 public:
  void reset() {
    count_ = 0;
    zone_count_ = 0;
    current_zone_ = -1;
    begin_absolute_zone();
  }

  // Open an absolute (1g) zone starting at the current sample position.
  void begin_absolute_zone() {
    if (zone_count_ < SA_MAX_ZONES)
      zones_[current_zone_ = zone_count_++] = {count_, 0.0f, SA_SCALE_ABS};
  }

  // Open a delta (0.1g) zone with the given baseline starting at current position.
  void begin_delta_zone(float baseline_g) {
    if (zone_count_ < SA_MAX_ZONES)
      zones_[current_zone_ = zone_count_++] = {count_, baseline_g, SA_SCALE_DELTA};
  }

  void push(float weight_g) {
    if (count_ >= SA_MAX_SAMPLES || current_zone_ < 0) return;
    const ZoneEntry &z = zones_[current_zone_];
    float val = weight_g - z.baseline_g;
    if (z.scale != SA_SCALE_ABS) val *= z.scale;
    samples_[count_++] = static_cast<int16_t>(
        std::max(-32768.0f, std::min(32767.0f, val)));
  }

  int count() const { return count_; }

  /**
   * Motion metric for an ELIMINATING period — matches TS processEvent:
   * slice [start+10, end+1-10), decode to grams, eliminatingPeriodMotionMetric(..., hz=10).
   *
   * No heap: decodes window-by-window; RMS list uses sa_motion_rms_scratch() BSS.
   */
  float elimination_motion_metric(int start, int end, int hz) const {
    const int trim = 10;
    int s = start + trim;
    int e = end + 1 - trim;
    if (s >= e || s < 0 || e > count_) return -1.0f;
    int n = e - s;
    if (n < 2) return -1.0f;

    const int ws = hz >= 1 ? hz : 1;
    if (n < ws) return rms_around_mean_range(s, n);

    const int window_count = n / ws;
    if (window_count > SA_MAX_MOTION_WINDOWS) return -1.0f;

    float *rms_values = sa_motion_rms_scratch();
    for (int w = 0; w < window_count; ++w)
      rms_values[w] = rms_around_mean_range(s + w * ws, ws);

    std::sort(rms_values, rms_values + window_count);
    const int mid = window_count / 2;
    if (window_count % 2)
      return rms_values[mid];
    return 0.5f * (rms_values[mid - 1] + rms_values[mid]);
  }

 private:
  const ZoneEntry *zone_for_index(int idx) const {
    for (int z = 0; z < zone_count_; ++z) {
      int next_start = (z + 1 < zone_count_) ? zones_[z + 1].start : count_;
      if (idx >= zones_[z].start && idx < next_start) return &zones_[z];
    }
    return nullptr;
  }

  float sample_to_grams(int idx) const {
    const ZoneEntry *z = zone_for_index(idx);
    if (!z || idx < 0 || idx >= count_) return 0.0f;
    float enc = static_cast<float>(samples_[idx]);
    if (z->scale == SA_SCALE_ABS) return enc;
    return z->baseline_g + enc / static_cast<float>(z->scale);
  }

  /** TS rmsAroundMean over decoded grams in [s, s+n) without a heap decode buffer. */
  float rms_around_mean_range(int s, int n) const {
    if (n < 2) return 0.0f;
    float sum = 0.0f;
    for (int i = 0; i < n; ++i) sum += sample_to_grams(s + i);
    float mean = sum / static_cast<float>(n);
    float sq = 0.0f;
    for (int i = 0; i < n; ++i) {
      float d = sample_to_grams(s + i) - mean;
      sq += d * d;
    }
    return sqrtf(sq / static_cast<float>(n));
  }
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

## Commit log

2025-06-05 add individual daily visits sensors
2025-06-05 refactor common reset event logic into script
    [litterbox-monitor.yaml]
2025-06-05 reset state after inactivity timeout
    [litterbox-monitor.yaml]
2025-06-06 rename weight sensors
2025-09-07 fix: execute timeout script in restart mode
    [litterbox-monitor.yaml]
2025-09-10 feat: add runtime calibration
2025-09-11 fix: add back cat weight setting after event
    [litterbox-monitor.yaml]
2025-09-11 fix: increase event timeout to better capture outlier events
    [litterbox-monitor.yaml]
2025-09-12 fix: invert event inactivity timeout triggers
    [litterbox-monitor.yaml]
2026-04-13 Feat/poop sense
    * feat: PoopSense
    * revert two-yaml template approach as unsupported by esphome
    * docs: add PoopSense readme
    * improve state analyzer int accuracy & docs
    [litterbox-monitor.yaml, state_analyzer.h]
2026-07-11 fix(analyzer): correct stability, weight, and elimination detection
    Compare sqrt(sample variance) for stability instead of raw variance.
    Average cat weight over stable eliminating windows instead of exponential
    smoothing. Classify elimination motion with median-RMS windows rather than
    population std dev. Raise transition and period limits for long oscillating
    visits.
    [state_analyzer.h]
2026-07-12 feat: add per cat daily pee/poop sensors
2026-07-19 fix(analyzer): move finalize scratch buffers off loop stack
    Move StateResult, period-processing scratch space, and motion RMS
    storage into persistent BSS-backed storage. Return the finalized result
    by const reference and avoid transient vector allocations.
    This prevents finalize() from exceeding the ESPHome loop task's 8 KiB
    stack and causing crashes or corrupted state after litterbox events.
    [litterbox-monitor.yaml, state_analyzer.h]
2026-08-06 docs: restructure into build-journey README and load cell guide
    Reorder the README as a build journey (features -> BOM -> assembly ->
    firmware -> calibration -> reference) instead of usage-before-hardware.
    Rewrite the intro and features in plain language and remove sections
    repeating each other.
    Move load cell sizing into docs/LOAD_CELLS.md: capacity formula with a
    temperament-based jump factor, off-center loading rationale, worked
    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
2026-08-19 feat: add WiFi signal strength diagnostic sensor
    Publish RSSI in dBm, sampled at 15 s and sent as the median of four, so
    a bars gauge tracks the link rather than the sample-to-sample jitter at
    the same once-a-minute chatter.
    Matches the sensor added to the ESPHome fountains and bowl monitor in
    oddware, which cat-health picks up by device class with no changes on
    that side.
    [litterbox-monitor.yaml]
2026-08-20 feat: publish deep-clean due timestamp and honest countdown
    Adds a Deep Clean Due timestamp sensor — a fact that survives reboots
    on both ends and needs no clock to compute, so API clients get it in
    the initial state dump. The Deep Clean Timer stops lying at the edges:
    NAN until a deadline has ever been set (0 claimed one nobody set),
    fractional so the last day still counts down, and negative once
    overdue instead of clamping "expired yesterday" and "expired last
    month" to the same 0. The reset button ignores presses while the clock
    is unsynced rather than stamping a 1970 litter change.
    [litterbox-monitor.yaml]
2026-08-26 feat: add full litter weight config and litter level percentage
    Litter Remaining is only meaningful next to a full box, so add a
    "Full Litter Weight" number to say what a fresh fill weighs and a
    "Litter Level" percentage driven off it. Left at 0 the percentage
    reports unknown rather than dividing by a guess, and the result is
    clamped so an overfilled box or a drifted scale can't read 104%
    or -3%.
    [litterbox-monitor.yaml]
2026-09-06 feat: box tracking — detect scoops, top-ups, deep cleans and lifts
    Run a BoxMonitor on the absolute (un-tared) weight so the bare board,
    the empty box and poured litter are recognisable shapes rather than
    ambiguous deltas. At event end it classifies what the human did:
    - deep_clean: box returns within 150 g of Empty Box Weight; litter,
    waste and visits reset and the deep-clean timer restarts
    - top_up: plateaus rise monotonically and go inert (σ < 1 g) for 30 s,
    which no cat can do, so the bag is litter whatever it weighs
    - scoop: ≥ 20 g out, after 30 s or any absence of the box
    - lifted: monitor or box back within tolerance, nothing changes
    Also folds bare-board drift into the cal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
    [litterbox-monitor.yaml, state_analyzer.h]
2026-09-12 feat(cad): FreeCAD enclosure — brain shell, load-cell feet, HX711 tray, cable channels
    Parametric FreeCAD scripts for the printed parts that hang under the
    KOMPLEMENT board, plus the exported STL/STEP and the saved FCStd docs.
    - brain_shell.py: S3 Super Mini shell on the front edge, split into Top
    (nose, LED under it) and Mid (skirt + tail), with Sleeve, TailSleeve
    and CapSleeve inserts. Rev 2 layout: components up, board on the -X half.
    - foot.py: load-cell foot — base, cap and 1.0 mm shim, rebuilt from the
    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
    [assembly.FCStd, brain_shell.FCStd, brain_shell_cap.step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]
2026-09-12 experiment(cad): PartDesign timeline generators for every printed part
    Parked, not the product. Each *_param.py rebuilds its part as a PartDesign
    document — one Params spreadsheet, fully constrained sketches with every
    dimension an expression on the sheet, and a Pad / Pocket / Fillet / Mirrored /
    AdditivePipe / Boolean timeline per Body — so the design can be scrubbed and
    edited in the FreeCAD GUI. pdlib.py holds the shared helpers and the compare
    harness that checks each body against the shape the original script builds.
    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
